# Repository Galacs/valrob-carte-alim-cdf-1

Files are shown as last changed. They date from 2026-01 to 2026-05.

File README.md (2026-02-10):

# Carte alim CDF 1

ESP32-S3-WROOM-1 5v 10A and 12v 10A six efuse protected with current and state monitoring channels power supply boards

The repo also contains minimal firmware for the ESP32 MCU.

## IC List

- ESP32-S3-WROOM-1 (Main MCU Module)
- TLV757P (MCU 3v3 LDO)
- 2X TPS56A37 (10A smps)
- SN65HVD (CAN transceiver)
- 7x TPS259472 (5A efuse)

## Top preview



## Preview 3d render



## Pictures




## Pin definitions

```c
#define PWR_STATUS_PIN 17

#define PG_12V_PIN 37
#define PG_5V_PIN 48
#define VSENSE_PIN 17

#define CAN_RX 35
#define CAN_TX 36

#define BAU 42

#define ILM_5V_1_PIN 1
#define ILM_5V_2_PIN 3
#define ILM_5V_3_PIN 2

#define ILM_12V_1_PIN 1
#define ILM_12V_2_PIN 7
#define ILM_12V_3_PIN 5
#define ILM_12V_4_PIN 4

#define EN_5V_1_PIN 39
#define EN_5V_2_PIN 21
#define EN_5V_3_PIN 40

#define EN_12V_1_PIN 11
#define EN_12V_2_PIN 13
#define EN_12V_3_PIN 8

#define PG_5V_1_PIN 38
#define PG_5V_2_PIN 47
#define PG_5V_3_PIN 41

#define PG_12V_1_PIN 10
#define PG_12V_2_PIN 12
#define PG_12V_3_PIN 18
#define PG_12V_4_PIN 16
```

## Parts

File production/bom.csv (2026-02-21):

Designator | Footprint | Quantity | Value | LCSC Part #
BT1 | Power battery holder | 1 | 18v
C1, C11, C12, C15, C16, C5, C6 | 0402 | 7 | 0u1 | C307331
C10, C7, C8, C9 | 0805 | 4 | 10u | C440198
C13, C14, C4 | 0603 | 3 | 22u | C59461
C17, C18 | 0402 | 2 | 47p | C1567
C19, C20, C21, C22, C23, C24, C25, C26 | 0805 | 8 | 22u | C45783
C2 | 0603 | 1 | 10u | C19702
C27, C3, C30, C33, C36, C39, C42, C45 | 0402 | 8 | 1u | C52923
C29, C32, C35, C38, C41, C44, C47 | 0402 | 7 | 1n | C1523
D1, D2, D5 | Diode_DFN1006 | 3 | H5VU10U | C22395519
D10, D4, D9 | 0603 | 3 | RED | C2286
D11, D20, D6 | D_SMA | 3 | D_Schottky | C22452
D12, D13, D14, D15, D16, D17, D18, D19, D3 | 0805 | 9 | GREEN | C2297
D7 | D_SOD-123 | 1 | BZT52B3V3 | C19077392
D8 | D_SMA | 1 | D_TVS | C19077549
J1 | USB_C_Receptacle_HRO_TYPE-C-31-M-12 | 1 | USB_C_Receptacle_USB2.0_14P | C393939
J10, J11, J12, J13, J14, J15, J16, J17, J18, J19, J2, J20, J21, J22, J4, J5, J6, J7, J8, J9 | JST_XH_B2B-XH-A_1x02_P2.50mm_Vertical | 20 | Conn_01x02 | C158012
JP10, JP3, JP4, JP5, JP6, JP7, JP8, JP9 | PinHeader_2x01_P2.54mm_Vertical | 8 | Jumper_2_Small_Open
L1, L2 | L_Bourns_SRP1050WA | 2 | 5u6 | C149541
R1, R12, R13, R16, R17, R2, R24, R25, R27, R31, R32, R34, R38, R4, R40, R46, R48, R5, R54, R56, R62, R64, R70, R71, R73 | 0402 | 25 | 5k1 | C25905
R10, R11 | 0402 | 2 | 22 | C25092
R14, R15 | 0402 | 2 | 52k3 | C26982
R18, R21, R26, R28, R33, R35, R41, R43, R49, R51, R57, R59, R6, R65, R67, R72, R8, R9 | 0402 | 18 | 10k | C25744
R19 | 0402 | 1 | 100k | C25741
R20 | 0402 | 1 | 73k2 | C26986
R22, R23, R29, R30, R36, R37, R42, R44, R45, R50, R52, R53, R58, R60, R61, R66, R68, R69 | 0402 | 18 | 1k5 | C25867
R3 | 1206 | 1 | 120 | C17909
R39, R47, R55, R63 | 0402 | 4 | 390k | C25782
R7 | 0603 | 1 | 1k8 | C4177
SW1 | JST_XH_B2B-XH-A_1x02_P2.50mm_Vertical | 1 | SW_Push | C158012
SW2, SW3 | SW_SPST_TS-1088-xR020 | 2 | SW_Push | C720477
U1 | SOIC-8_3.9x4.9mm_P1.27mm | 1 | SN65HVD230 | C12084
U10, U11, U12, U6, U7, U8, U9 | Texas_RPW0010A_VQFN-HR-10_2x2mm_P0.5mm | 7 | TPS259472A | C3662789
U3 | SOT-23-5 | 1 | TLV75733PDBV | C485517
U4, U5 | Texas_RPA0010A_VQFN-HR-10_3x3mm_P0.5mm | 2 | TPS56A37 | C22392669

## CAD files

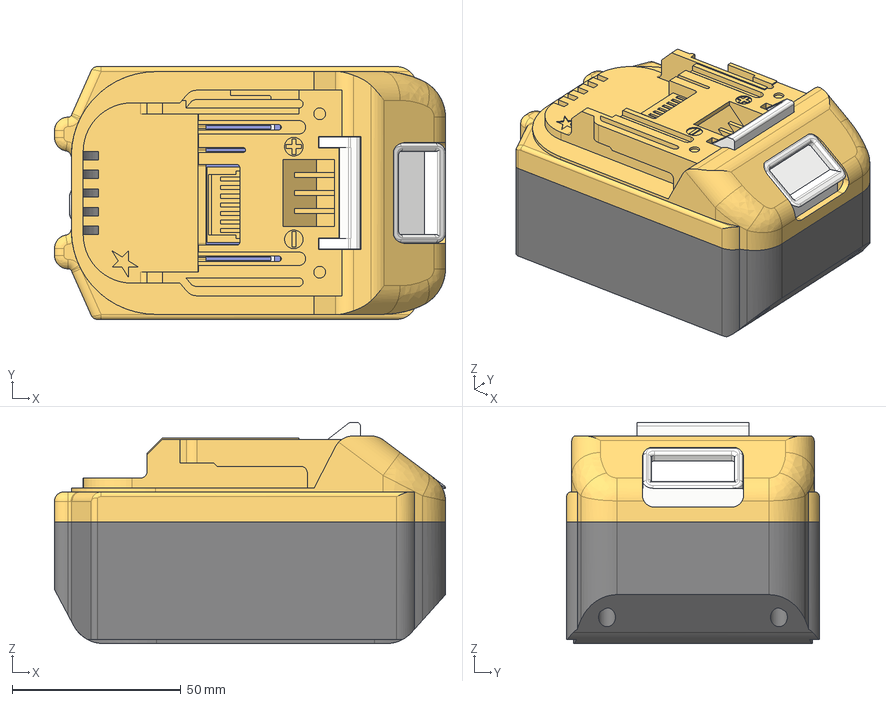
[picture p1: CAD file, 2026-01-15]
step/Battery LxT 18V v7.step
116.0 x 75.0 x 65.6 mm
Battery Plate
Battery Clip
Yellow Connector
Power Clips
Case

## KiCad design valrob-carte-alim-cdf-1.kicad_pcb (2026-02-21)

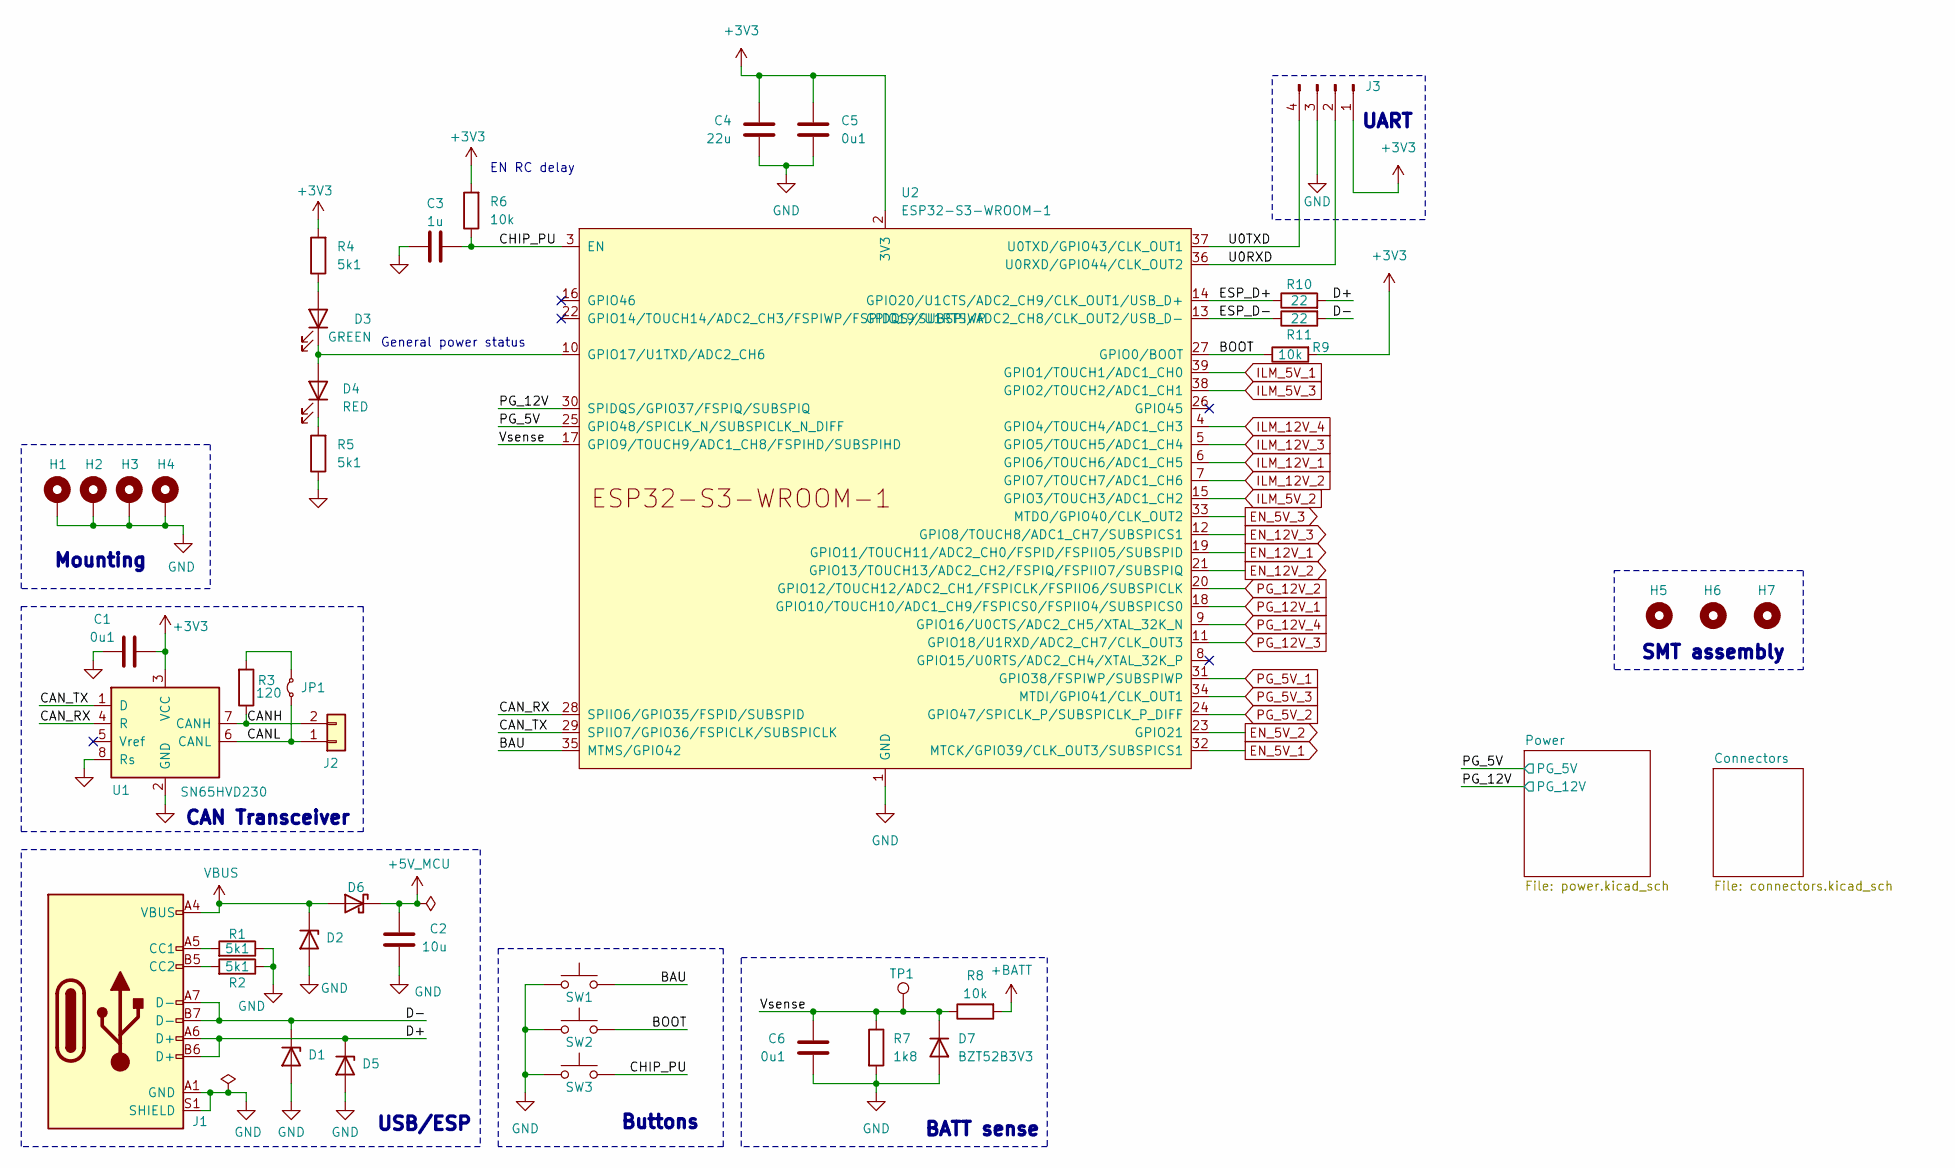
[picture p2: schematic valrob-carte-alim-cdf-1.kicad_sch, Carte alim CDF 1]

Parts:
C1, C5, C6: 0u1; C_0402_1005Metric; Manufacturer Part Number CL05B104KB54PNC; JLCPCB Part # C307331
C2: 10u; C_0603_1608Metric; Manufacturer Part Number CL10A106KP8NNNC; JLCPCB Part # C19702
C3: 1u; C_0402_1005Metric; Manufacturer Part Number CL05A105KA5NQNC; JLCPCB Part # C52923
C4: 22u; C_0603_1608Metric; Manufacturer Part Number CL10A226MQ8NRNC; JLCPCB Part # C59461
D1, D2, D5: H5VU10U; Diode_DFN1006; Manufacturer Part Number H5VU10U; JLCPCB Part # C22395519
D3: GREEN; LED_0805_2012Metric; Manufacturer Part Number KT-0805G; JLCPCB Part # C2297
D4: RED; LED_0603_1608Metric; Manufacturer Part Number KT-0603R; JLCPCB Part # C2286
D6: D_Schottky; D_SMA; Manufacturer Part Number SS54; JLCPCB Part # C22452
D7: BZT52B3V3; D_SOD-123; Manufacturer Part Number BZT52B3V3; JLCPCB Part # C19077392
H1, H2, H3, H4: MountingHole_Pad; MountingHole_2.2mm_M2_Pad_Via
H5, H6, H7: MountingHole; ToolingHole_1.152mm
J1: USB_C_Receptacle_USB2.0_14P; USB_C_Receptacle_HRO_TYPE-C-31-M-12; Manufacturer Part Number TYPE-C16PIN; JLCPCB Part # C393939
J2: Conn_01x02; JST_XH_B2B-XH-A_1x02_P2.50mm_Vertical; Manufacturer Part Number B2B-XH-A(LF)(SN); JLCPCB Part # C158012
J3: Conn_01x04_Pin; PinHeader_1x04_P2.54mm_Vertical
JP1: Jumper_2_Small_Bridged; SolderJumper-2_P1.3mm_Open_RoundedPad1.0x1.5mm
R1, R2, R4, R5: 5k1; R_0402_1005Metric; Manufacturer Part Number 0402WGF5101TCE; JLCPCB Part # C25905
R3: 120; R_1206_3216Metric; Manufacturer Part Number 1206W4F1200T5E; JLCPCB Part # C17909
R6, R8, R9: 10k; R_0402_1005Metric; Manufacturer Part Number 0402WGF1002TCE; JLCPCB Part # C25744
R7: 1k8; R_0603_1608Metric; Manufacturer Part Number 0603WAF1801T5E; JLCPCB Part # C4177
R10, R11: 22; R_0402_1005Metric; Manufacturer Part Number 0402WGF220JTCE; JLCPCB Part # C25092
SW1: SW_Push; JST_XH_B2B-XH-A_1x02_P2.50mm_Vertical; Manufacturer Part Number B2B-XH-A(LF)(SN); JLCPCB Part # C158012
SW2, SW3: SW_Push; SW_SPST_TS-1088-xR020; Manufacturer Part Number TS-1088-AR02016; JLCPCB Part # C720477
TP1: TestPoint; TestPoint_Pad_D2.0mm
U1: SN65HVD230; SOIC-8_3.9x4.9mm_P1.27mm; Manufacturer Part Number SN65HVD230DR; JLCPCB Part # C12084
U2: ESP32-S3-WROOM-1; Manufacturer Part Number ESP32-S3-WROOM-1-N8R2; JLCPCB Part # C2913204

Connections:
+3V3: C1.1, C4.1, C5.1, J3.1, R4.2, R6.2, R9.2, U1.3 (VCC), U2.2 (3V3); also elsewhere on the board
+5V_MCU: C2.1, D6.1 (K); also elsewhere on the board
+BATT: R8.2; also elsewhere on the board
/BAU: SW1.2, U2.35 (MTMS/GPIO42)
/BOOT: R9.1, SW2.2, U2.27 (GPIO0/BOOT)
/CANH: J2.2, R3.1, U1.7 (CANH)
/CANL: J2.1, JP1.1 (A), U1.6 (CANL)
/CAN_RX: U1.4 (R), U2.28 (SPIIO6/GPIO35/FSPID/SUBSPID)
/CAN_TX: U1.1 (D), U2.29 (SPIIO7/GPIO36/FSPICLK/SUBSPICLK)
/CHIP_PU: C3.2, R6.1, SW3.2, U2.3 (EN)
/D+: D5.1 (K), J1.A6 (D+), J1.B6 (D+), R10.2
/D-: D1.1 (K), J1.A7 (D-), J1.B7 (D-), R11.2
/ESP_D+: R10.1, U2.14 (GPIO20/U1CTS/ADC2_CH9/CLK_OUT1/USB_D+)
/ESP_D-: R11.1, U2.13 (GPIO19/U1RTS/ADC2_CH8/CLK_OUT2/USB_D-)
/PG_5V: U2.25 (GPIO48/SPICLK_N/SUBSPICLK_N_DIFF); also elsewhere on the board
/PG_12V: U2.30 (SPIDQS/GPIO37/FSPIQ/SUBSPIQ); also elsewhere on the board
/U0RXD: J3.2, U2.36 (U0RXD/GPIO44/CLK_OUT2)
/U0TXD: J3.4, U2.37 (U0TXD/GPIO43/CLK_OUT1)
/Vsense: C6.1, D7.1 (K), R7.1, R8.1, TP1.1, U2.17 (GPIO9/TOUCH9/ADC1_CH8/FSPIHD/SUBSPIHD)
EN_5V_1: U2.32 (MTCK/GPIO39/CLK_OUT3/SUBSPICS1); also elsewhere on the board
EN_5V_2: U2.23 (GPIO21); also elsewhere on the board
EN_5V_3: U2.33 (MTDO/GPIO40/CLK_OUT2); also elsewhere on the board
EN_12V_1: U2.19 (GPIO11/TOUCH11/ADC2_CH0/FSPID/FSPIIO5/S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); also elsewhere on the board
EN_12V_2: U2.21 (GPIO13/TOUCH13/ADC2_CH2/FSPIQ/FSPIIO7/S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); also elsewhere on the board
EN_12V_3: U2.12 (GPIO8/TOUCH8/ADC1_CH7/SUBSPICS1); also elsewhere on the board
GND: C1.2, C2.2, C3.1, C4.2, C5.2, C6.2, D1.2 (A), D2.2 (A), D5.2 (A), D7.2 (A), H1.1, H2.1, H3.1, H4.1, J1.A1 (GND), J1.A12 (GND), J1.B1 (GND), J1.B12 (GND), J1.S1 (SHIELD), J3.3, R1.1, R2.1, R5.1, R7.2, SW1.1, SW2.1, SW3.1, U1.2 (GND), U1.8 (Rs), U2.1 (GND), U2.40 (GND), U2.41 (GND); also elsewhere on the board
ILM_5V_1: U2.39 (GPIO1/TOUCH1/ADC1_CH0); also elsewhere on the board
ILM_5V_2: U2.15 (GPIO3/TOUCH3/ADC1_CH2); also elsewhere on the board
ILM_5V_3: U2.38 (GPIO2/TOUCH2/ADC1_CH1); also elsewhere on the board
ILM_12V_1: U2.6 (GPIO6/TOUCH6/ADC1_CH5); also elsewhere on the board
ILM_12V_2: U2.7 (GPIO7/TOUCH7/ADC1_CH6); also elsewhere on the board
ILM_12V_3: U2.5 (GPIO5/TOUCH5/ADC1_CH4); also elsewhere on the board
ILM_12V_4: U2.4 (GPIO4/TOUCH4/ADC1_CH3); also elsewhere on the board
unnamed: D3.2 (A), R4.1
unnamed: D3.1 (K), D4.2 (A), U2.10 (GPIO17/U1TXD/ADC2_CH6)
unnamed: D4.1 (K), R5.2
unnamed: J1.A5 (CC1), R1.2
unnamed: J1.B5 (CC2), R2.2
unnamed: JP1.2 (B), R3.2
PG_5V_1: U2.31 (GPIO38/FSPIWP/SUBSPIWP); also elsewhere on the board
PG_5V_2: U2.24 (GPIO47/SPICLK_P/SUBSPICLK_P_DIFF); also elsewhere on the board
PG_5V_3: U2.34 (MTDI/GPIO41/CLK_OUT1); also elsewhere on the board
PG_12V_1: U2.18 (GPIO10/TOUCH10/ADC1_CH9/FSPICS0/FSPIIO4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); also elsewhere on the board
PG_12V_2: U2.20 (GPIO12/TOUCH12/ADC2_CH1/FSPICLK/FSPIIO6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); also elsewhere on the board
PG_12V_3: U2.11 (GPIO18/U1RXD/ADC2_CH7/CLK_OUT3); also elsewhere on the board
PG_12V_4: U2.9 (GPIO16/U0CTS/ADC2_CH5/XTAL_32K_N); also elsewhere on the board
VBUS: D2.1 (K), D6.2 (A), J1.A4 (VBUS), J1.A9 (VBUS), J1.B4 (VBUS), J1.B9 (VBUS)

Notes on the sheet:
EN RC delay
Mounting
SMT assembly
UART
Buttons
USB/ESP
BATT sense
CAN Transceiver
General power status

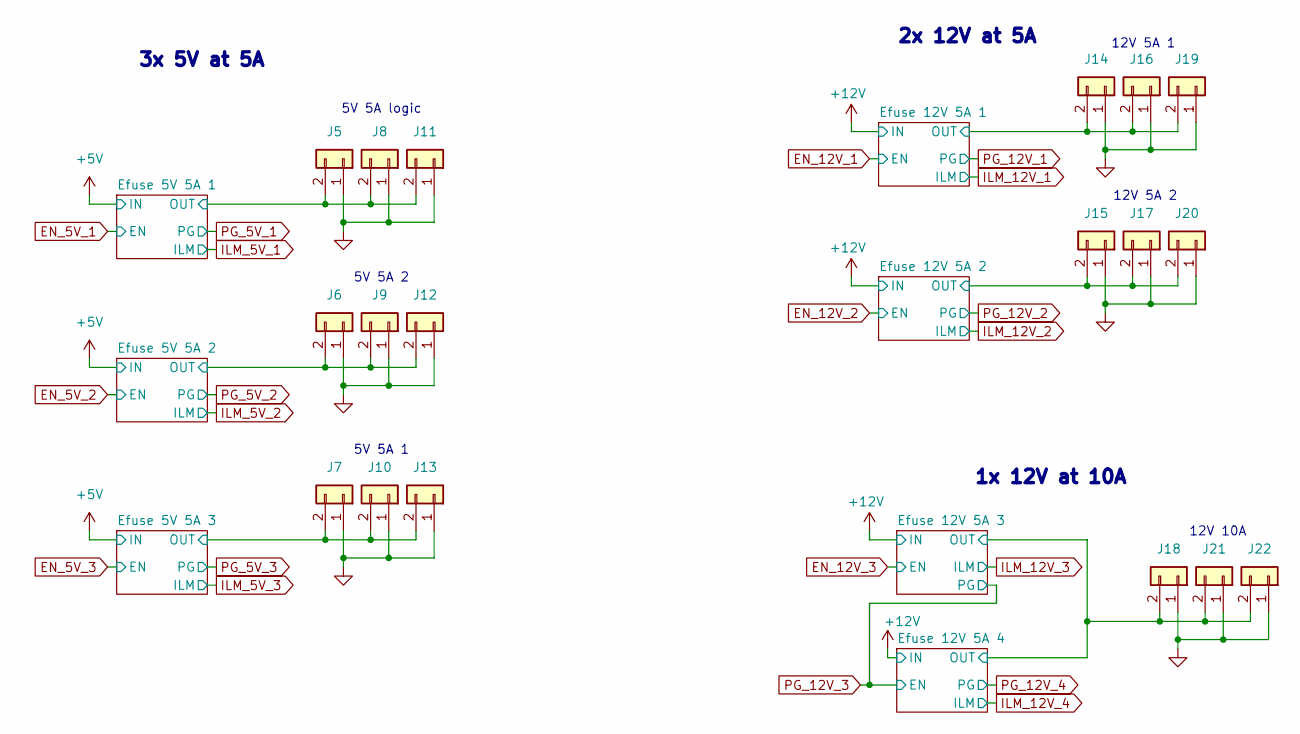
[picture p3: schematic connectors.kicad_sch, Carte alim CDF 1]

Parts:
J5, J6, J7, J8, J9, J10, J11, J12, J13, J14, J15, J16, J17, J18, J19, J20, J21, J22: Conn_01x02; JST_XH_B2B-XH-A_1x02_P2.50mm_Vertical; Manufacturer Part Number B2B-XH-A(LF)(SN); JLCPCB Part # C158012

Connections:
/Connectors/Efuse 5V 5A 1/OUT: J5.2, J8.2, J11.2; also elsewhere on the board
/Connectors/Efuse 5V 5A 2/OUT: J6.2, J9.2, J12.2; also elsewhere on the board
/Connectors/Efuse 5V 5A 3/OUT: J7.2, J10.2, J13.2; also elsewhere on the board
/Connectors/Efuse 12V 5A 1/OUT: J14.2, J16.2, J19.2; also elsewhere on the board
/Connectors/Efuse 12V 5A 2/OUT: J15.2, J17.2, J20.2; also elsewhere on the board
/Connectors/Efuse 12V 5A 3/OUT: J18.2, J21.2, J22.2; also elsewhere on the board
GND: J5.1, J6.1, J7.1, J8.1, J9.1, J10.1, J11.1, J12.1, J13.1, J14.1, J15.1, J16.1, J17.1, J18.1, J19.1, J20.1, J21.1, J22.1; also elsewhere on the board

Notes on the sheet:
5V 5A 1
12V 5A 2
12V 5A 1
2x 12V at 5A
1x 12V at 10A
12V 10A
5V 5A 2
3x 5V at 5A
5V 5A logic

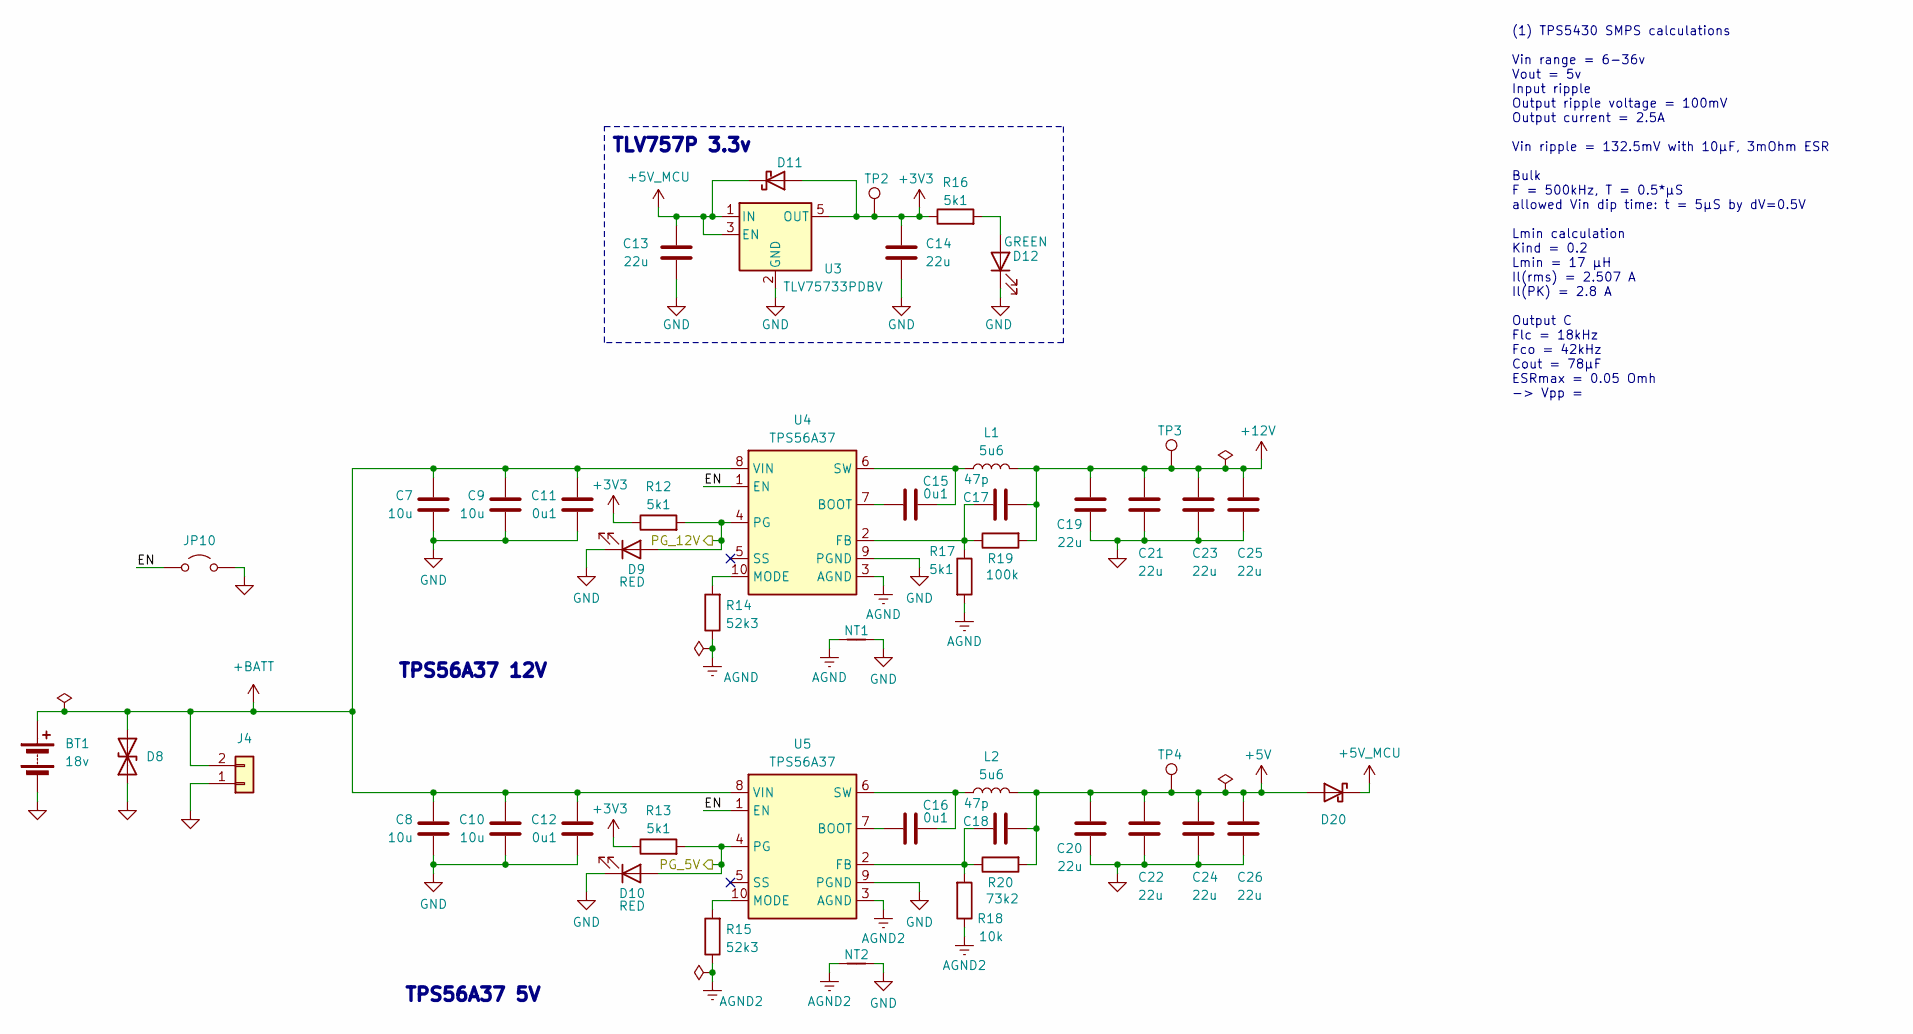
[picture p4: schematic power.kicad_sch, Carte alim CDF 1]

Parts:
BT1: 18v; Power battery holder
C7, C8, C9, C10: 10u; C_0805_2012Metric; Manufacturer Part Number GRM21BR61H106KE43L; JLCPCB Part # C440198
C11, C12, C15, C16: 0u1; C_0402_1005Metric; Manufacturer Part Number CL05B104KB54PNC; JLCPCB Part # C307331
C13, C14: 22u; C_0603_1608Metric; Manufacturer Part Number CL10A226MQ8NRNC; JLCPCB Part # C59461
C17, C18: 47p; C_0402_1005Metric; Manufacturer Part Number 0402CG470J500NT; JLCPCB Part # C1567
C19, C20, C21, C22, C23, C24, C25, C26: 22u; C_0805_2012Metric; Manufacturer Part Number CL21A226MAQNNNE; JLCPCB Part # C45783
D8: D_TVS; D_SMA; Manufacturer Part Number SMAJ33CA; JLCPCB Part # C19077549
D9, D10: RED; LED_0603_1608Metric; Manufacturer Part Number KT-0603R; JLCPCB Part # C2286
D11, D20: D_Schottky; D_SMA; Manufacturer Part Number SS54; JLCPCB Part # C22452
D12: GREEN; LED_0805_2012Metric; Manufacturer Part Number KT-0805G; JLCPCB Part # C2297
J4: Conn_01x02; JST_XH_B2B-XH-A_1x02_P2.50mm_Vertical; Manufacturer Part Number B2B-XH-A(LF)(SN); JLCPCB Part # C158012
JP10: Jumper_2_Small_Open; PinHeader_2x01_P2.54mm_Vertical
L1, L2: 5u6; L_Bourns_SRP1050WA; Manufacturer Part Number SMMS1050-5R6M; JLCPCB Part # C149541
NT1, NT2: NetTie_2; NetTie-2_SMD_Pad0.5mm
R12, R13, R16, R17: 5k1; R_0402_1005Metric; Manufacturer Part Number 0402WGF5101TCE; JLCPCB Part # C25905
R14, R15: 52k3; R_0402_1005Metric; Manufacturer Part Number 0402WGF5232TCE; JLCPCB Part # C26982
R18: 10k; R_0402_1005Metric; Manufacturer Part Number 0402WGF1002TCE; JLCPCB Part # C25744
R19: 100k; R_0402_1005Metric; Manufacturer Part Number 0402WGF1003TCE; JLCPCB Part # C25741
R20: 73k2; R_0402_1005Metric; Manufacturer Part Number 0402WGF7322TCE; JLCPCB Part # C26986
TP2, TP3, TP4: TestPoint; TestPoint_Pad_D2.0mm
U3: TLV75733PDBV; SOT-23-5; Manufacturer Part Number TLV75733PDBVR; JLCPCB Part # C485517
U4, U5: TPS56A37; Texas_RPA0010A_VQFN-HR-10_3x3mm_P0.5mm; Manufacturer Part Number TPS56A37RPAR; JLCPCB Part # C22392669

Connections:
+3V3: C14.2, D11.2 (A), R12.1, R13.1, R16.1, TP2.1, U3.5 (OUT); also elsewhere on the board
+5V: C18.2, C20.1, C22.1, C24.1, C26.1, D20.2 (A), L2.2, R20.2, TP4.1; also elsewhere on the board
+5V_MCU: C13.2, D11.1 (K), D20.1 (K), U3.1 (IN), U3.3 (EN); also elsewhere on the board
+12V: C17.2, C19.1, C21.1, C23.1, C25.1, L1.2, R19.2, TP3.1; also elsewhere on the board
+BATT: BT1.1 (+), C7.1, C8.1, C9.1, C10.1, C11.1, C12.1, D8.2 (A2), J4.2, U4.8 (VIN), U5.8 (VIN); also elsewhere on the board
/PG_5V: D10.2 (A), R13.2, U5.4 (PG); also elsewhere on the board
/PG_12V: D9.2 (A), R12.2, U4.4 (PG); also elsewhere on the board
/Power/EN: JP10.1 (A), U4.1 (EN), U5.1 (EN)
AGND: NT1.1, R14.1, R17.2, U4.3 (AGND)
AGND2: NT2.1, R15.1, R18.1, U5.3 (AGND)
GND: BT1.2 (-), C7.2, C8.2, C9.2, C10.2, C11.2, C12.2, C13.1, C14.1, C19.2, C20.2, C21.2, C22.2, C23.2, C24.2, C25.2, C26.2, D8.1 (A1), D9.1 (K), D10.1 (K), D12.1 (K), J4.1, JP10.2 (B), NT1.2, NT2.2, U3.2 (GND), U4.9 (PGND), U5.9 (PGND); also elsewhere on the board
unnamed: D12.2 (A), R16.2
unnamed: C15.1, U4.7 (BOOT)
unnamed: C17.1, R17.1, R19.1, U4.2 (FB)
unnamed: R14.2, U4.10 (MODE)
unnamed: C15.2, L1.1, U4.6 (SW)
unnamed: C16.1, U5.7 (BOOT)
unnamed: C18.1, R18.2, R20.1, U5.2 (FB)
unnamed: R15.2, U5.10 (MODE)
unnamed: C16.2, L2.1, U5.6 (SW)

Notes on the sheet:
TPS56A37 12V
TLV757P 3.3v
TPS56A37 5V
(1) TPS5430 SMPS calculations Vin range = 6-36v Vout = 5v Input ripple Output ripple voltage = 100mV Output current = 2.5A Vin ripple = 132.5mV with 10µF, 3mOhm ESR Bulk F = 500kHz, T = 0.5*µS allowed Vin dip time: t = 5µS by dV=0.5V Lmin calculation Kind = 0.2 Lmin = 17 µH Il(rms) = 2.507 A Il(PK)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

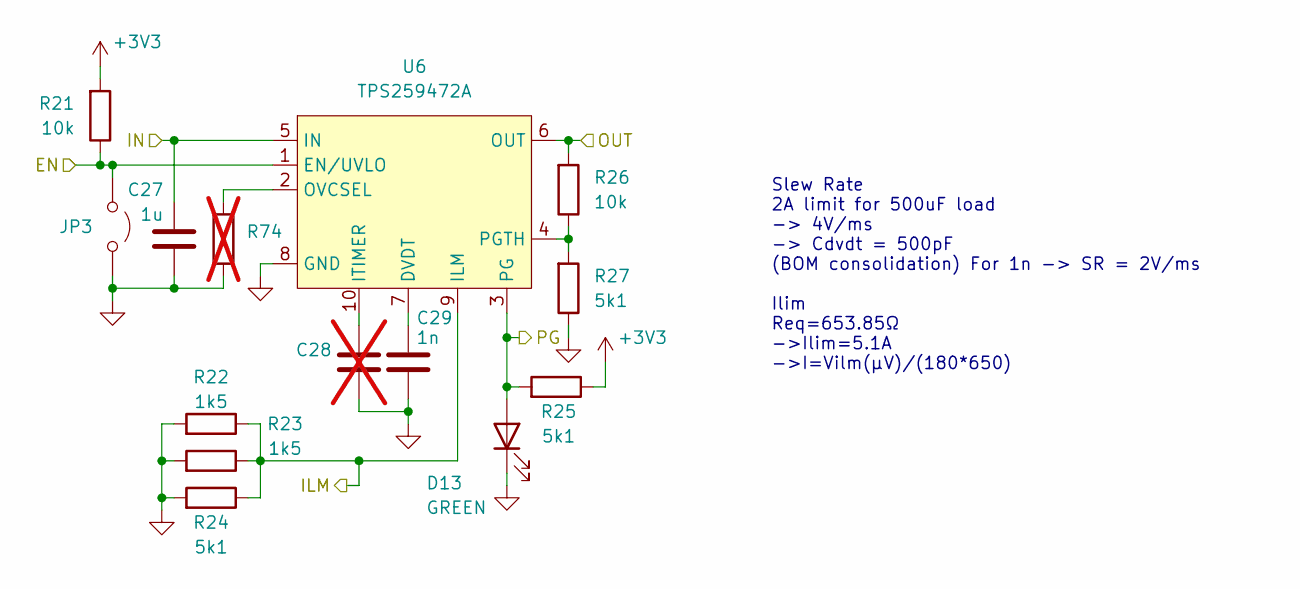
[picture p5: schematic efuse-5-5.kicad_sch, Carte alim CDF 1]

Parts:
C27: 1u; C_0402_1005Metric; Manufacturer Part Number CL05A105KA5NQNC; JLCPCB Part # C52923
C28: C; C_0402_1005Metric; not fitted
C29: 1n; C_0402_1005Metric; Manufacturer Part Number 0402B102K500NT; JLCPCB Part # C1523
D13: GREEN; LED_0805_2012Metric; Manufacturer Part Number KT-0805G; JLCPCB Part # C2297
JP3: Jumper_2_Small_Open; PinHeader_2x01_P2.54mm_Vertical
R21, R26: 10k; R_0402_1005Metric; Manufacturer Part Number 0402WGF1002TCE; JLCPCB Part # C25744
R22, R23: 1k5; R_0402_1005Metric; Manufacturer Part Number 0402WGF1501TCE; JLCPCB Part # C25867
R24, R25, R27: 5k1; R_0402_1005Metric; Manufacturer Part Number 0402WGF5101TCE; JLCPCB Part # C25905
R74: R; R_0402_1005Metric; not fitted
U6: TPS259472A; Texas_RPW0010A_VQFN-HR-10_2x2mm_P0.5mm; Manufacturer Part Number TPS259472ARPWR; JLCPCB Part # C3662789

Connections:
+3V3: R21.2, R25.1; also elsewhere on the board
+5V: C27.2, U6.5 (IN); also elsewhere on the board
/Connectors/Efuse 5V 5A 1/OUT: R26.2, U6.6 (OUT); also elsewhere on the board
EN_5V_1: JP3.1 (A), R21.1, U6.1 (EN/UVLO); also elsewhere on the board
GND: C27.1, C28.2, C29.2, D13.1 (K), JP3.2 (B), R22.2, R23.2, R24.2, R27.1, R74.2, U6.8 (GND); also elsewhere on the board
ILM_5V_1: R22.1, R23.1, R24.1, U6.9 (ILM); also elsewhere on the board
unnamed: C29.1, U6.7 (DVDT)
unnamed: C28.1, U6.10 (ITIMER)
unnamed: R74.1, U6.2 (OVCSEL)
unnamed: R26.1, R27.2, U6.4 (PGTH)
PG_5V_1: D13.2 (A), R25.2, U6.3 (PG); also elsewhere on the board

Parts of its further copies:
C30, C45: 1u; C_0402_1005Metric; Manufacturer Part Number CL05A105KA5NQNC; JLCPCB Part # C52923
C31, C46: C; C_0402_1005Metric; not fitted
C32, C47: 1n; C_0402_1005Metric; Manufacturer Part Number 0402B102K500NT; JLCPCB Part # C1523
D14, D19: GREEN; LED_0805_2012Metric; Manufacturer Part Number KT-0805G; JLCPCB Part # C2297
JP4, JP9: Jumper_2_Small_Open; PinHeader_2x01_P2.54mm_Vertical
R28, R33, R67, R72: 10k; R_0402_1005Metric; Manufacturer Part Number 0402WGF1002TCE; JLCPCB Part # C25744
R29, R30, R68, R69: 1k5; R_0402_1005Metric; Manufacturer Part Number 0402WGF1501TCE; JLCPCB Part # C25867
R31, R32, R34, R70, R71, R73: 5k1; R_0402_1005Metric; Manufacturer Part Number 0402WGF5101TCE; JLCPCB Part # C25905
R75, R76: R; R_0402_1005Metric; not fitted
U7, U12: TPS259472A; Texas_RPW0010A_VQFN-HR-10_2x2mm_P0.5mm; Manufacturer Part Number TPS259472ARPWR; JLCPCB Part # C3662789

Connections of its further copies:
+3V3: R28.2, R32.1, R67.2, R71.1; also elsewhere on the board
+5V: C30.2, C45.2, U7.5 (IN), U12.5 (IN); also elsewhere on the board
/Connectors/Efuse 5V 5A 2/OUT: R72.2, U12.6 (OUT); also elsewhere on the board
/Connectors/Efuse 5V 5A 3/OUT: R33.2, U7.6 (OUT); also elsewhere on the board
EN_5V_2: JP9.1 (A), R67.1, U12.1 (EN/UVLO); also elsewhere on the board
EN_5V_3: JP4.1 (A), R28.1, U7.1 (EN/UVLO); also elsewhere on the board
GND: C30.1, C31.2, C32.2, C45.1, C46.2, C47.2, D14.1 (K), D19.1 (K), JP4.2 (B), JP9.2 (B), R29.2, R30.2, R31.2, R34.1, R68.2, R69.2, R70.2, R73.1, R75.2, R76.2, U7.8 (GND), U12.8 (GND); also elsewhere on the board
ILM_5V_2: R68.1, R69.1, R70.1, U12.9 (ILM); also elsewhere on the board
ILM_5V_3: R29.1, R30.1, R31.1, U7.9 (ILM); also elsewhere on the board
unnamed: C32.1, U7.7 (DVDT)
unnamed: C31.1, U7.10 (ITIMER)
unnamed: R75.1, U7.2 (OVCSEL)
unnamed: R33.1, R34.2, U7.4 (PGTH)
unnamed: C47.1, U12.7 (DVDT)
unnamed: C46.1, U12.10 (ITIMER)
unnamed: R76.1, U12.2 (OVCSEL)
unnamed: R72.1, R73.2, U12.4 (PGTH)
PG_5V_2: D19.2 (A), R71.2, U12.3 (PG); also elsewhere on the board
PG_5V_3: D14.2 (A), R32.2, U7.3 (PG); also elsewhere on the board

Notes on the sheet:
Slew Rate 2A limit for 500uF load -> 4V/ms -> Cdvdt = 500pF (BOM consolidation) For 1n -> SR = 2V/ms Ilim Req=653.85Ω ->Ilim=5.1A ->I=Vilm(µV)/(180*650)

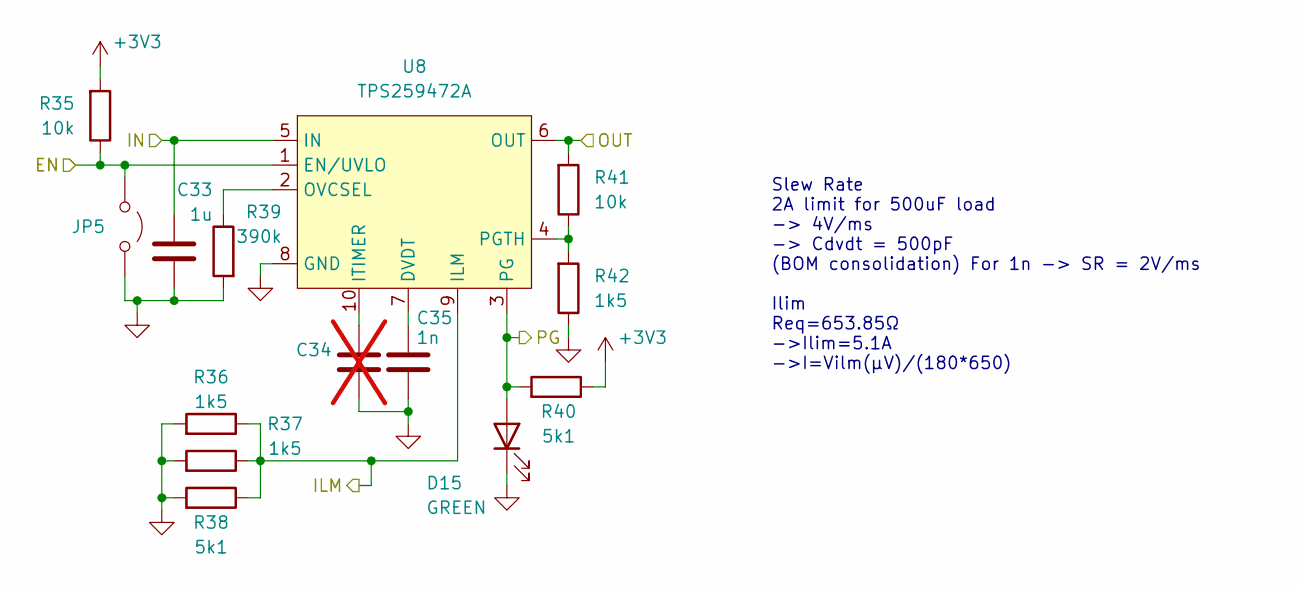
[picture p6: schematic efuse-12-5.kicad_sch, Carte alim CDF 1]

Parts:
C33: 1u; C_0402_1005Metric; Manufacturer Part Number CL05A105KA5NQNC; JLCPCB Part # C52923
C34: C; C_0402_1005Metric; not fitted
C35: 1n; C_0402_1005Metric; Manufacturer Part Number 0402B102K500NT; JLCPCB Part # C1523
D15: GREEN; LED_0805_2012Metric; Manufacturer Part Number KT-0805G; JLCPCB Part # C2297
JP5: Jumper_2_Small_Open; PinHeader_2x01_P2.54mm_Vertical
R35, R41: 10k; R_0402_1005Metric; Manufacturer Part Number 0402WGF1002TCE; JLCPCB Part # C25744
R36, R37, R42: 1k5; R_0402_1005Metric; Manufacturer Part Number 0402WGF1501TCE; JLCPCB Part # C25867
R38, R40: 5k1; R_0402_1005Metric; Manufacturer Part Number 0402WGF5101TCE; JLCPCB Part # C25905
R39: 390k; R_0402_1005Metric; Manufacturer Part Number 0402WGF3903TCE; JLCPCB Part # C25782
U8: TPS259472A; Texas_RPW0010A_VQFN-HR-10_2x2mm_P0.5mm; Manufacturer Part Number TPS259472ARPWR; JLCPCB Part # C3662789

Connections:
+3V3: R35.2, R40.1; also elsewhere on the board
+12V: C33.2, U8.5 (IN); also elsewhere on the board
/Connectors/Efuse 12V 5A 1/OUT: R41.2, U8.6 (OUT); also elsewhere on the board
EN_12V_1: JP5.1 (A), R35.1, U8.1 (EN/UVLO); also elsewhere on the board
GND: C33.1, C34.2, C35.2, D15.1 (K), JP5.2 (B), R36.2, R37.2, R38.2, R39.2, R42.1, U8.8 (GND); also elsewhere on the board
ILM_12V_1: R36.1, R37.1, R38.1, U8.9 (ILM); also elsewhere on the board
unnamed: C35.1, U8.7 (DVDT)
unnamed: C34.1, U8.10 (ITIMER)
unnamed: R39.1, U8.2 (OVCSEL)
unnamed: R41.1, R42.2, U8.4 (PGTH)
PG_12V_1: D15.2 (A), R40.2, U8.3 (PG); also elsewhere on the board

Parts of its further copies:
C36, C39, C42: 1u; C_0402_1005Metric; Manufacturer Part Number CL05A105KA5NQNC; JLCPCB Part # C52923
C37, C40, C43: C; C_0402_1005Metric; not fitted
C38, C41, C44: 1n; C_0402_1005Metric; Manufacturer Part Number 0402B102K500NT; JLCPCB Part # C1523
D16, D17, D18: GREEN; LED_0805_2012Metric; Manufacturer Part Number KT-0805G; JLCPCB Part # C2297
JP6, JP7, JP8: Jumper_2_Small_Open; PinHeader_2x01_P2.54mm_Vertical
R43, R49, R51, R57, R59, R65: 10k; R_0402_1005Metric; Manufacturer Part Number 0402WGF1002TCE; JLCPCB Part # C25744
R44, R45, R50, R52, R53, R58, R60, R61, R66: 1k5; R_0402_1005Metric; Manufacturer Part Number 0402WGF1501TCE; JLCPCB Part # C25867
R46, R48, R54, R56, R62, R64: 5k1; R_0402_1005Metric; Manufacturer Part Number 0402WGF5101TCE; JLCPCB Part # C25905
R47, R55, R63: 390k; R_0402_1005Metric; Manufacturer Part Number 0402WGF3903TCE; JLCPCB Part # C25782
U9, U10, U11: TPS259472A; Texas_RPW0010A_VQFN-HR-10_2x2mm_P0.5mm; Manufacturer Part Number TPS259472ARPWR; JLCPCB Part # C3662789

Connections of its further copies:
+3V3: R43.2, R48.1, R51.2, R56.1, R59.2, R64.1; also elsewhere on the board
+12V: C36.2, C39.2, C42.2, U9.5 (IN), U10.5 (IN), U11.5 (IN); also elsewhere on the board
/Connectors/Efuse 12V 5A 2/OUT: R49.2, U9.6 (OUT); also elsewhere on the board
/Connectors/Efuse 12V 5A 3/OUT: R57.2, R65.2, U10.6 (OUT), U11.6 (OUT); also elsewhere on the board
EN_12V_2: JP6.1 (A), R43.1, U9.1 (EN/UVLO); also elsewhere on the board
EN_12V_3: JP7.1 (A), R51.1, U10.1 (EN/UVLO); also elsewhere on the board
GND: C36.1, C37.2, C38.2, C39.1, C40.2, C41.2, C42.1, C43.2, C44.2, D16.1 (K), D17.1 (K), D18.1 (K), JP6.2 (B), JP7.2 (B), JP8.2 (B), R44.2, R45.2, R46.2, R47.2, R50.1, R52.2, R53.2, R54.2, R55.2, R58.1, R60.2, R61.2, R62.2, R63.2, R66.1, U9.8 (GND), U10.8 (GND), U11.8 (GND); also elsewhere on the board
ILM_12V_2: R44.1, R45.1, R46.1, U9.9 (ILM); also elsewhere on the board
ILM_12V_3: R52.1, R53.1, R54.1, U10.9 (ILM); also elsewhere on the board
ILM_12V_4: R60.1, R61.1, R62.1, U11.9 (ILM); also elsewhere on the board
unnamed: C38.1, U9.7 (DVDT)
unnamed: C37.1, U9.10 (ITIMER)
unnamed: R47.1, U9.2 (OVCSEL)
unnamed: R49.1, R50.2, U9.4 (PGTH)
unnamed: C41.1, U10.7 (DVDT)
unnamed: C40.1, U10.10 (ITIMER)
unnamed: R55.1, U10.2 (OVCSEL)
unnamed: R57.1, R58.2, U10.4 (PGTH)
unnamed: C44.1, U11.7 (DVDT)
unnamed: C43.1, U11.10 (ITIMER)
unnamed: R63.1, U11.2 (OVCSEL)
unnamed: R65.1, R66.2, U11.4 (PGTH)
PG_12V_2: D16.2 (A), R48.2, U9.3 (PG); also elsewhere on the board
PG_12V_3: D17.2 (A), JP8.1 (A), R56.2, R59.1, U10.3 (PG), U11.1 (EN/UVLO); also elsewhere on the board
PG_12V_4: D18.2 (A), R64.2, U11.3 (PG); also elsewhere on the board

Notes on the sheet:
Slew Rate 2A limit for 500uF load -> 4V/ms -> Cdvdt = 500pF (BOM consolidation) For 1n -> SR = 2V/ms Ilim Req=653.85Ω ->Ilim=5.1A ->I=Vilm(µV)/(180*650)

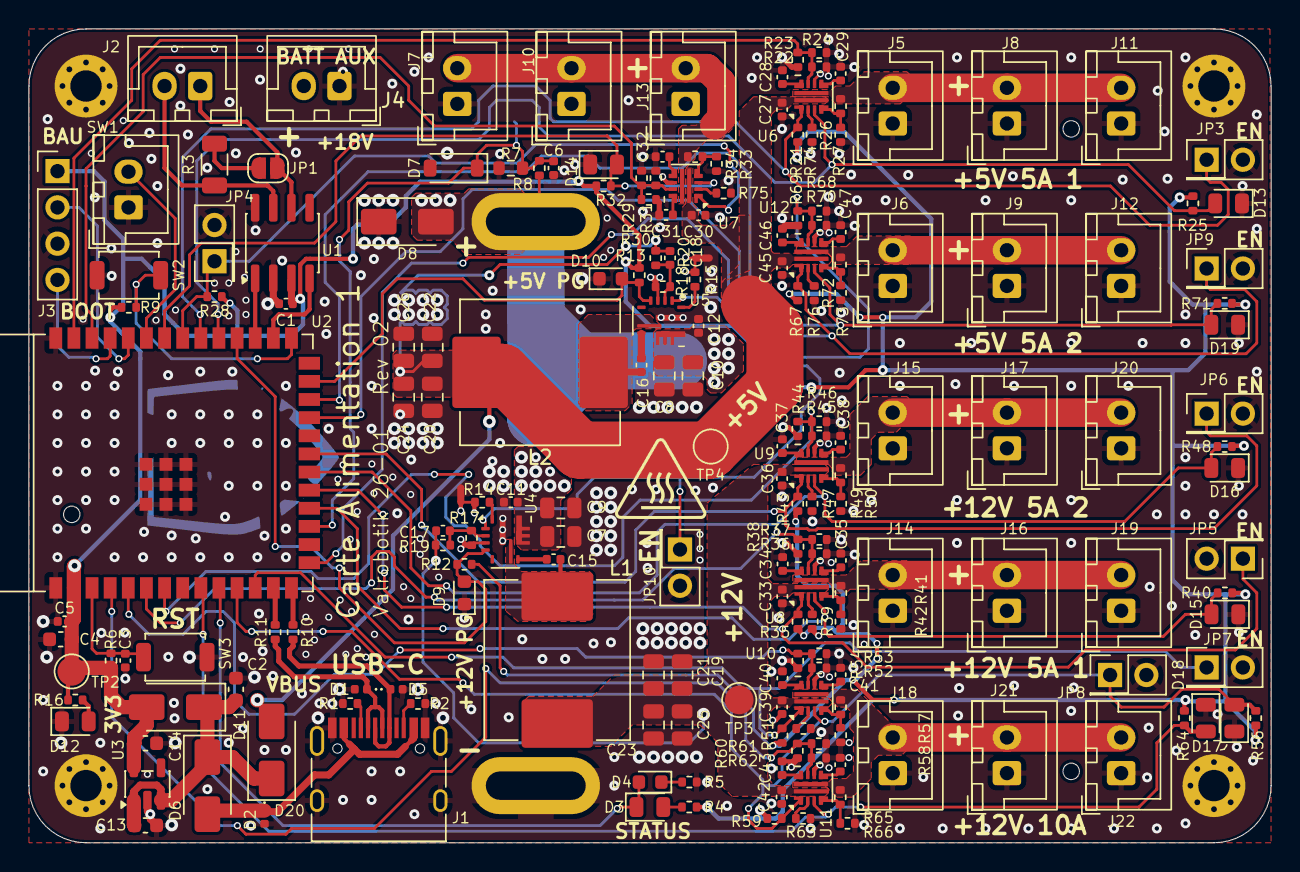
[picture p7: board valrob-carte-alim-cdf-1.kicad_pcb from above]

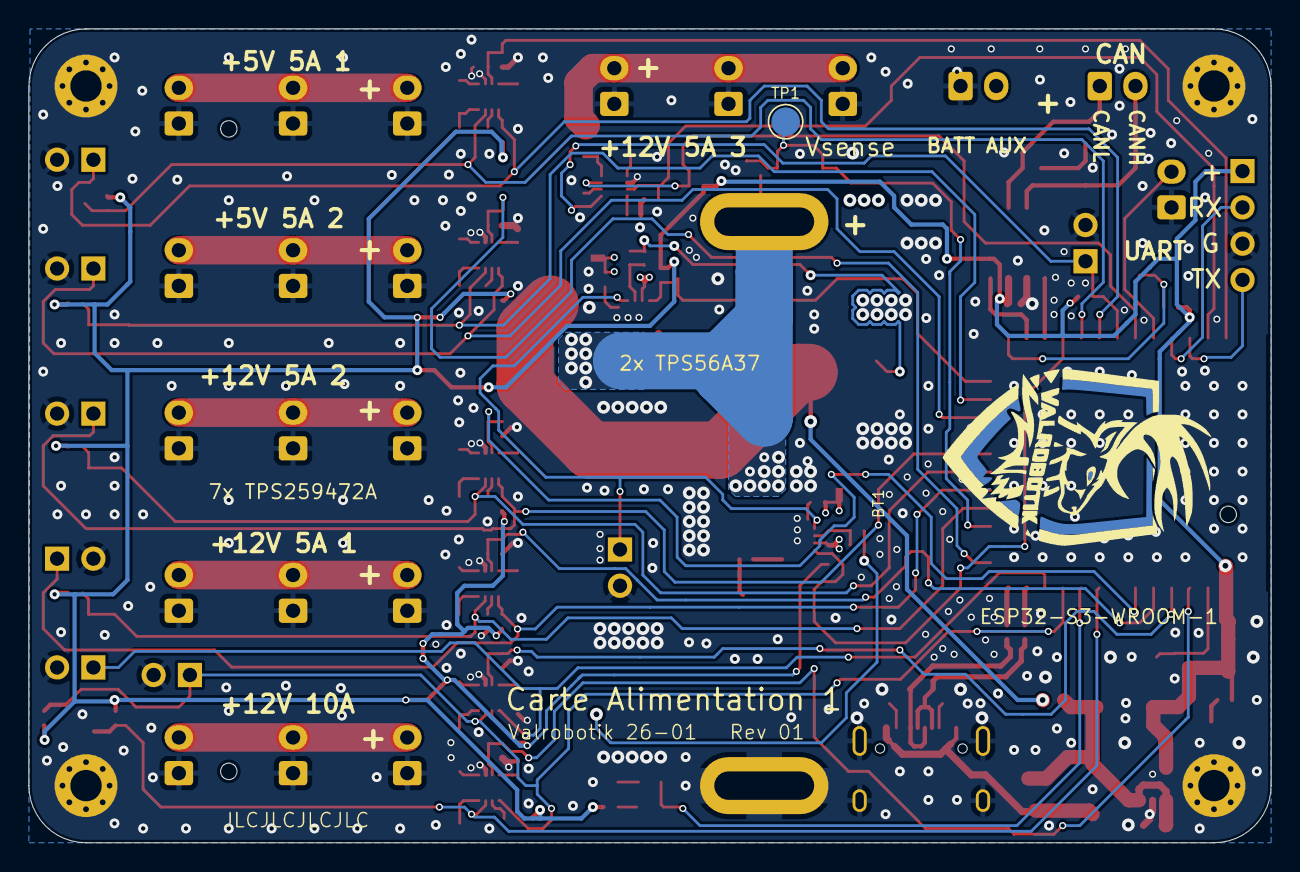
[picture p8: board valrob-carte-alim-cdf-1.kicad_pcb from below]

Board: 4 copper layers, 87.0 x 57.0 mm, 205 parts (2 on the bottom side), 95 nets.

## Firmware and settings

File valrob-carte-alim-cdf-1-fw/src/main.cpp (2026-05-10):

#include <Arduino.h>
#include <Commander.h>

#define PWR_STATUS_PIN 17

#define PG_12V_PIN 37
#define PG_5V_PIN 48
#define VSENSE_PIN 17

#define CAN_RX 35
#define CAN_TX 36

#define BAU 42

#define ILM_5V_1_PIN 1
#define ILM_5V_2_PIN 3
#define ILM_5V_3_PIN 2

#define ILM_12V_1_PIN 1
#define ILM_12V_2_PIN 7
#define ILM_12V_3_PIN 5
#define ILM_12V_4_PIN 4

#define EN_5V_1_PIN 39
#define EN_5V_2_PIN 21
#define EN_5V_3_PIN 40

#define EN_12V_1_PIN 11
#define EN_12V_2_PIN 13
#define EN_12V_3_PIN 8

#define PG_5V_1_PIN 38
#define PG_5V_2_PIN 47
#define PG_5V_3_PIN 41

#define PG_12V_1_PIN 10
#define PG_12V_2_PIN 12
#define PG_12V_3_PIN 18
#define PG_12V_4_PIN 16

bool every_ms(unsigned long* last_run, unsigned long time) {
  if (millis() > *last_run + time) {
    *last_run = millis();
    return true;
  }
  return false;
}

enum class power_channel_state_t: uint8_t {
  GOOD,
  OVERRIDE,
  EMS,
  FAULT,
  OFF,
};

class PowerChannel {
public:
  PowerChannel(int en_pin, int pg_pin, int ilm_pin, String channel_name,
               bool enabled = true, float ilim = -1)
      : m_en_pin(en_pin), m_pg_pin(pg_pin), m_ilm_pin(ilm_pin),
        m_channel_name(channel_name), m_mcu_low(!enabled), m_soft_Ilim(ilim),
        m_last_good(0) {
    pinMode(m_en_pin, INPUT);
    pinMode(m_pg_pin, INPUT);
    pinMode(m_ilm_pin, INPUT);
    analogSetAttenuation(adc_attenuation_t::ADC_0db);
    if (enabled) {
      enable();
    }
  };

  void trigger_EMS() {
    m_ems = true;
    pinMode(m_en_pin, OUTPUT);
    digitalWrite(m_en_pin, LOW);
  };
  void release_EMS() {
    m_ems = false;
    if (!m_mcu_low) {
      pinMode(m_en_pin, INPUT);
    } else {
      pinMode(m_en_pin, INPUT);
    }
  };

  void disable() {
    pinMode(m_en_pin, OUTPUT);
    m_mcu_low = true;
    digitalWrite(m_en_pin, LOW);
  };

  void enable() {
    if (m_ems) return;
    pinMode(m_en_pin, INPUT);
    m_mcu_low = false;
  };

  // true pg and no low en
  power_channel_state_t get_state() {
    if (m_mcu_low) return power_channel_state_t::OFF;
    if (m_ems) return power_channel_state_t::EMS;
    if (!m_mcu_low && !digitalRead(m_en_pin)) return power_channel_state_t::OVERRIDE;
    if (!m_mcu_low && digitalRead(m_en_pin) && !digitalRead(m_pg_pin) && millis() - m_last_good < 150)
      return power_channel_state_t::GOOD;
    if (!m_mcu_low && digitalRead(m_en_pin) && !digitalRead(m_pg_pin)) return power_channel_state_t::FAULT;
    m_last_good = millis();
    return power_channel_state_t::GOOD;
  }

  float get_current() {
    return (analogReadMilliVolts(m_ilm_pin)/1000)/645*182;
  }

  String get_name() {
    return m_channel_name;
  }

  void print_state() {
    const static String states[] = {"GOOD", "OVERRIDE", "EMS", "FAULT", "OFF"};
    Serial.printf("%s: %s, I: %fA\n", m_channel_name, states[(uint8_t) get_state()], get_current());
  }

  bool is_good() {
    return get_state() != power_channel_state_t::FAULT;
  }

private:
  int m_en_pin;
  int m_pg_pin;
  int m_ilm_pin;
  String m_channel_name;
  bool m_mcu_low;
  bool m_override_low;
  bool m_pg;
  bool m_ems = false;
  float m_current;
  float m_soft_Ilim;
  unsigned int m_last_good;
};

float get_batt_volotage() {
  return 0.0;
}

PowerChannel Channel_5v_1(EN_5V_1_PIN, PG_5V_1_PIN, ILM_5V_1_PIN, "+5V 5A 1");
PowerChannel Channel_5v_2(EN_5V_2_PIN, PG_5V_2_PIN, ILM_5V_2_PIN, "+5V 5A 2");

PowerChannel Channel_12v_1(EN_12V_1_PIN, PG_12V_1_PIN, ILM_12V_1_PIN, "+12V 5A 1");
PowerChannel Channel_12v_2(EN_12V_2_PIN, PG_12V_2_PIN, ILM_12V_2_PIN, "+12V 5A 2");
PowerChannel Channel_12v_3(EN_12V_3_PIN, PG_12V_4_PIN, ILM_12V_3_PIN, "+12V 10A");

static PowerChannel* channels[] = {&Channel_5v_1, &Channel_5v_2, &Channel_12v_1, &Channel_12v_2, &Channel_12v_3};

static PowerChannel* ems_dis_channels[] = {&Channel_5v_1, &Channel_5v_2, &Channel_12v_1, &Channel_12v_2, &Channel_12v_3};

Commander command = Commander(Serial);

uint ctouint(char c) {
  return c - '0';
}

void doDisableChannel(char* cmd) {
  uint channel = ctouint(cmd[0]);
  if (channel >= 1 && channel <= 5) {
    channels[channel]->disable();
    Serial.printf("Disabled %s\n", channels[channel]->get_name());
  }
}

void doEnableChannel(char* cmd) {
  uint channel = ctouint(cmd[0]);
  if (channel >= 1 && channel <= 5) {
    channels[channel]->enable();
    Serial.printf("Enabled %s\n", channels[channel]->get_name());
  }
}

void setup() {
  Serial.begin(115200);
  pinMode(PWR_STATUS_PIN, OUTPUT);
  pinMode(BAU, INPUT_PULLUP);

  command.add('E', doEnableChannel);
  command.add('D', doDisableChannel);
}

unsigned long last_pwr_led_blink = 0;
bool pwr_led_state = false;
void update_pwr_led(bool ems) {
  bool is_good = true;
  for (size_t i = 0; i < sizeof(channels)/sizeof(PowerChannel*); i++) {
    is_good &= channels[i]->is_good();
  }
  if (!digitalRead(BAU)) {
    digitalWrite(PWR_STATUS_PIN, !is_good);
  } else if (every_ms(&last_pwr_led_blink, 200)) {
    digitalWrite(PWR_STATUS_PIN, pwr_led_state);
    pwr_led_state = !pwr_led_state;
  }
}


bool update_ems() {
  if (digitalRead(BAU)) {
    for (size_t i = 0; i < sizeof(ems_dis_channels)/sizeof(PowerChannel*); i++) {
      ems_dis_channels[i]->trigger_EMS();
    }
    return true;
  } else {
    for (size_t i = 0; i < sizeof(ems_dis_channels)/sizeof(PowerChannel*); i++) {
      ems_dis_channels[i]->release_EMS();
    }
    return false;
  }
}

unsigned long last_pwr_led_update = 0;
unsigned long last_serial_update = 0;

void loop() {
  if (every_ms(&last_pwr_led_update, 10)) {
    update_pwr_led(update_ems());
  }
  if (every_ms(&last_serial_update, 500)) {
    Serial.println("channels status:");
    for (size_t i = 0; i < sizeof(channels)/sizeof(PowerChannel*); i++) {
      channels[i]->print_state();
    }
  }
  command.run();
}

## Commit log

2026-01-14 schem: add ESP32-S3-WROOM-1 MCU
    [valrob-carte-alim-cdf-1.kicad_sch]
2026-01-14 schem: add USBC connector
    [valrob-carte-alim-cdf-1.kicad_sch]
2026-01-14 schem: add TPS5430 5v logic SMPS
    [valrob-carte-alim-cdf-1.kicad_sch]
2026-01-14 schem: moved TSP5430 to power sheet
    [power.kicad_sch, valrob-carte-alim-cdf-1.kicad_sch]
2026-01-14 schem: add efuse page
    [efuse.kicad_sch, power.kicad_sch]
2026-01-14 schem: add BOOT and CHIP_PU btns
    [valrob-carte-alim-cdf-1.kicad_sch]
2026-01-14 schem: add TPS259472A efuse
    [efuse.kicad_sch, power.kicad_sch]
2026-01-14 schem: add TPS56A37 12V SMPS
    [power.kicad_sch]
2026-01-14 schem: add TPS56A37 5V SMPS
    [power.kicad_sch, valrob-carte-alim-cdf-1.kicad_sch]
2026-01-14 schem: add battery esd tvs diode
    [power.kicad_sch]
2026-01-14 schem: add TPS259472A 5V 5A efuse
    [efuse-12-5.kicad_sch, efuse-5-5.kicad_sch, power.kicad_sch]
2026-01-14 schem: add VBUS TO +5V jumper
    [valrob-carte-alim-cdf-1.kicad_sch]
2026-01-14 schem: add 2 5V rails
    [connectors.kicad_sch, efuse-12-5.kicad_sch, efuse-5-5.kicad_sch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]
2026-01-14 schem: add 2 12V 5A rails
    [connectors.kicad_sch, efuse-12-5.kicad_sch, efuse-5-5.kicad_sch]
2026-01-14 schem: add ILM pins and 12V 10A rail
    [connectors.kicad_sch, efuse-12-5.kicad_sch, efuse-5-5.kicad_sch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]
2026-01-14 schem: add TLV757P 3.3v LDO
    [valrob-carte-alim-cdf-1.kicad_sch]
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2026-01-14 schem: add +BATT voltage sense
    [valrob-carte-alim-cdf-1.kicad_sch]
2026-01-14 schem: add CAN transceiver
    [power.kicad_sch, valrob-carte-alim-cdf-1.kicad_sch]
2026-01-14 schem: add additional connector for batt vin
    [power.kicad_sch, valrob-carte-alim-cdf-1.kicad_sch]
2026-01-14 schem: update 12v efuse net labels
    [connectors.kicad_sch]
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2026-01-14 schem: update 12V efuse component class
    [efuse-12-5.kicad_sch]
2026-01-15 schem: remove logic 5V smps
    [power.kicad_sch]
2026-01-15 schem: removed 5V output
    [connectors.kicad_sch, efuse-5-5.kicad_sch]
2026-01-15 schem: add disable jumper to efuses
    [efuse-12-5.kicad_sch, efuse-5-5.kicad_sch, power.kicad_sch]
2026-01-15 schem: add esp32 gpio connections
    [valrob-carte-alim-cdf-1.kicad_sch]
2026-01-15 schem: add general power status leds
    [valrob-carte-alim-cdf-1.kicad_sch]
2026-01-15 schem: change aux batt power connector
    [power.kicad_sch]
2026-01-15 schem: add test points
    [power.kicad_sch]
2026-01-15 schem: run and fix ERC
    [connectors.kicad_sch, power.kicad_sch, valrob-carte-alim-cdf-1.kicad_sch]
2026-01-15 schem: add battery holder footprint
    [power.kicad_sch]
2026-01-15 schem: update TPS259472A symbol
    [efuse-12-5.kicad_sch, efuse-5-5.kicad_sch]
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2026-01-15 schem: add sheet title
    [connectors.kicad_sch, efuse-12-5.kicad_sch, efuse-5-5.kicad_sch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]
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2026-01-15 pcb: import stackup and constraints
    [valrob-carte-alim-cdf-1.kicad_pcb]
2026-01-15 pcb: import footprints from schema
    [valrob-carte-alim-cdf-1.kicad_pcb]
2026-01-15 pcb: add missing 3D models
    [valrob-carte-alim-cdf-1.kicad_pcb]
2026-01-15 pcb: add initial rough layout
    [valrob-carte-alim-cdf-1.kicad_pcb, valrob-carte-alim-cdf-1.kicad_sch]
2026-01-15 pcb: add battery step file
    [Battery LxT 18V v7.step]
2026-01-16 schem: add mounting holes
    [valrob-carte-alim-cdf-1.kicad_sch]
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2026-01-16 pcb: add smps layout
    [power.kicad_sch, valrob-carte-alim-cdf-1.kicad_pcb]
2026-01-16 pcb: add efuse layout
    [efuse-12-5.kicad_sch, efuse-5-5.kicad_sch, valrob-carte-alim-cdf-1.kicad_pcb]
2026-01-16 pcb: finish initial layout
    [valrob-carte-alim-cdf-1.kicad_pcb]
2026-01-16 pcb: line up 2.54 headers
    [valrob-carte-alim-cdf-1.kicad_pcb]
2026-01-16 pcb: add can layout
    [valrob-carte-alim-cdf-1.kicad_pcb, valrob-carte-alim-cdf-1.kicad_sch]
2026-01-16 pcb: add gnd planes
    [valrob-carte-alim-cdf-1.kicad_pcb]
2026-01-16 pcb: add grid/place origin
    [valrob-carte-alim-cdf-1.kicad_pcb]
2026-01-16 pcb: add gnd vias
    [valrob-carte-alim-cdf-1.kicad_pcb]
2026-01-16 pcb: add high I 12V and 5V pwr routing
    [valrob-carte-alim-cdf-1.kicad_pcb]
2026-01-16 pcb: add 5V SMPS routing
    [valrob-carte-alim-cdf-1.kicad_pcb]
2026-01-16 pcb: fix 12v copper pour appearance
    [valrob-carte-alim-cdf-1.kicad_pcb]
2026-01-16 pcb: add 12V SMPS routing
    [valrob-carte-alim-cdf-1.kicad_pcb]
2026-01-16 pcb: add usb routing
    [valrob-carte-alim-cdf-1.kicad_pcb]
2026-01-16 pcb: add can routing
    [valrob-carte-alim-cdf-1.kicad_pcb, valrob-carte-alim-cdf-1.kicad_sch]
2026-01-16 pcb: complete smps routing
    [valrob-carte-alim-cdf-1.kicad_pcb]
2026-01-16 pcb: add efuse 5v 3 routing
    [valrob-carte-alim-cdf-1.kicad_pcb]
2026-01-16 pcb: add esp and ldo 3v3 routing
    [valrob-carte-alim-cdf-1.kicad_pcb]
2026-01-16 schem: reorganize programmable gpios
    [valrob-carte-alim-cdf-1.kicad_pcb, valrob-carte-alim-cdf-1.kicad_sch]
2026-01-17 pcb: increase size of negative batt spokes
    [valrob-carte-alim-cdf-1.kicad_pcb]
2026-01-17 pcb: add local efuse routing
    [valrob-carte-alim-cdf-1.kicad_pcb]
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2026-01-17 pcb: add efuses' PG leds and en jumpers routing
    [valrob-carte-alim-cdf-1.kicad_pcb]
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2026-01-17 pcb: add missing efuse EN routing to MCU
    [valrob-carte-alim-cdf-1.kicad_pcb]
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2026-01-17 pcb: run and fix DRC
    [valrob-carte-alim-cdf-1.kicad_pcb]
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2026-01-21 schem/pcb: prevent TPS56A37 reverse current with new oringed 5v mcu rail
    [power.kicad_sch, valrob-carte-alim-cdf-1.kicad_pcb, valrob-carte-alim-cdf-1.kicad_sch]
2026-01-21 pcb: switch smps power capacitors zone connection to solid
    [valrob-carte-alim-cdf-1.kicad_pcb]
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2026-02-08 fw: fix channels ems states
    [main.cpp]
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2026-02-09 fw: fix linking issue
    [main.cpp]
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
